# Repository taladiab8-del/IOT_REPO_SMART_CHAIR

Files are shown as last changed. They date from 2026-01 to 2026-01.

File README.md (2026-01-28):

# Smart Chair

## About The Project
We are the students: **Tala Diab, Bshara Awwad, Kayan Deeb**.

our project is a smart chair system that detects sitting posture in real time using pressure and motion sensors and displays the results in an application. The system supports real-time posture detection, cloud-based posture tracking with history storage, and daily and weekly posture reports. It is unique in combining pressure-based and motion-based posture recognition, supporting multiple users with baseline recalibration, and running an embedded KNN machine-learning model directly on an ESP32 microcontroller.

---

## Our Project in Details
We use **two modes** in the project: **Training mode** and **Prediction mode**.

### Training mode (building the dataset)
Training mode is used to **build a larger dataset** that will later be used to predict the user’s posture using the **KNN** machine‑learning model.

**How it works:**
1. **Baseline step:** the user first sits in **Position #1 (straight back)** so the system can save a **baseline** (to support different users and recalibration).
2. The user then goes through the **6 supported positions** (1–6).
3. For each position:
   - The user indicates **which position it is**.
   - The ESP32 samples the **5 FSR sensors + MPU6050** and collects the data.
   - The sample is appended to our **dataset Excel file** (under `DataSet/`) that stores all labeled samples.

**note (button / switch behavior):**
- Each time the user wants to record a **new position sample**, they toggle the **training trigger** from **OFF → ON** (and follow the on‑screen / printed instructions).  
  This ensures each labeled sample is saved as a separate entry in the dataset.

### Prediction mode (real-time inference)
Prediction mode is used to **predict the current sitting posture** using the existing dataset and the embedded **KNN** model.

**How it works (step-by-step):**
1. **Run the prediction firmware** on the ESP32.
2. **Press the button to start.**
3. The user first sits in **Position #1 (straight back)** to save a **baseline**.
   - The baseline is saved to **personalize** the system and reduce the effect of user‑specific factors (e.g., weight distribution and individual seating style) that can affect prediction.
4. After baseline is saved, the user can sit in any posture. The ESP32 continuously predicts the posture using the **dataset + KNN model**.
5. The predicted posture is uploaded to **Firebase**, and the app shows the result immediately.

**Live update rate:**
- The Live Data screen is updated **every 10 seconds** or **immediately when the posture changes**.

---

## Supported Positions (Labels 1–6)
1) Normal sitting (straight back)  
2) Left leg up  
3) Right leg up  
4) Leaning forward  
5) Reclined / tilted back  
6) Rotational / moving posture (motion state)

---

## application (Flutter) – what’s inside
The Flutter app is connected to Firebase and supports **three users**. For each user, the app provides:

### 1) Live Data screen
- Shows the **current posture label** in real time.
- Updates **every 10 seconds** or **when the user changes posture**.

### 2) Daily Report
- Shows **total sitting time today**.
- Shows **which postures were used today**, including counts / distribution (e.g., how many times each posture was detected).

### 3) Weekly Report
- Similar to Daily Report, but aggregated over the **current week**.
- Includes a **comparison vs. last week** for the same user.

### Sitting-duration alert + mute
- If a user remains sitting continuously for **1 hour**, the app shows a **“Move”** message.
- The message can be muted using a **Mute** button so the notifications stop appearing. **Muting does not reset the sitting timer** (the timer keeps running).
- Standing up resets the sitting timer and allows future alerts.

---

## Folder Description
In this git you have the following folders:

- `code/` – application code (Arduino + Python)
  - `code/arduino_code/chair_predict/`
    - `chair_predict.ino` – Prediction mode firmware 
    - `dataset.h` – exported dataset/KNN parameters header
  - `code/arduino_code/chair_training/`
    - `chair_training.ino` – Training mode firmware (collects labeled samples)
  - `code/pyhton_code/`
    - `build_dataset.py` – builds/updates the dataset file during Training
    - `export_knn.py` – exports the KNN model/parameters into `dataset.h`
    - `dataset.h` – generated header ny running export_knn.py
    - `sensor_samples.xlsx` – dataset from training

- `flutter_app/`
  - `lib/` – **our main app code**.

- `DataSet/` – contains the dataset Excel file (`sensor_samples.xlsx`)
- `Positions/` – contains the image of the supported sitting positions (`positions.png`)
- `Documentation/` – contains the poster and the connection diagram (PNG + Fritzing `.fzz`)
- `Unit Tests/` – unit tests for individual hardware components (button / pressure sensor / motion sensor)

---

## Hardware

### Hardware Components
- 5 × FSR pressure sensors
- 1 × MPU6050 motion sensor (IMU)
- 5 × 300Ω resistors
- 1 × ON/OFF switch
- 1 × ESP32 microcontroller

---

## Used Libraries

### Arduino/ESP32 libraries used in this project
  - `WiFi.h`
  - `Wire.h`
  - `time.h`
- Firebase ESP Client:
  - `Firebase_ESP_Client.h`
  - `addons/TokenHelper.h`
  - `addons/RTDBHelper.h`
- Adafruit MPU6050:
  - `Adafruit_MPU6050.h`
- Adafruit Unified Sensor:
  - `Adafruit_Sensor.h`

---

## Connection diagram

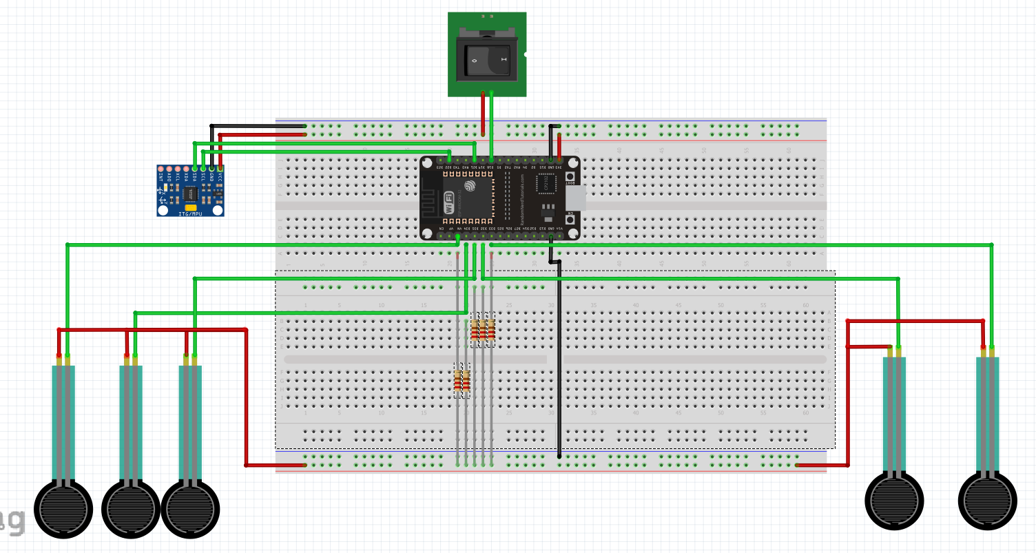
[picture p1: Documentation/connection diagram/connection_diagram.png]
Connection diagram


---

## Project Poster

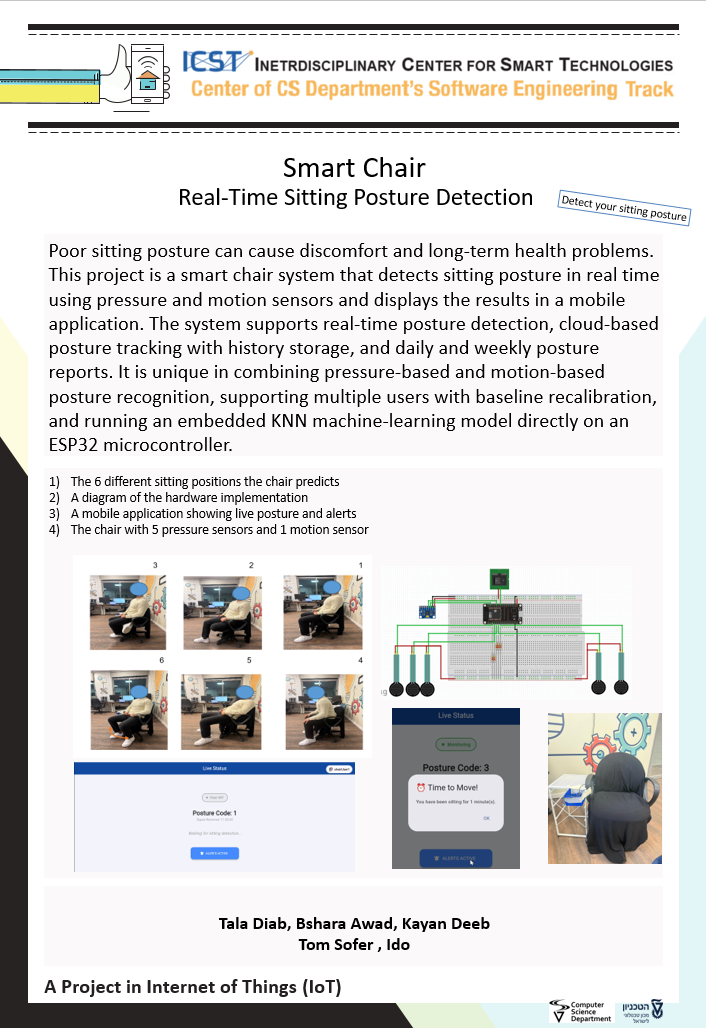
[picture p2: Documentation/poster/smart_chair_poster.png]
Smart Chair Poster


This project is part of ICST - The Interdisciplinary Center for Smart Technologies, Taub Faculty of Computer Science, Technion
https://icst.cs.technion.ac.il/

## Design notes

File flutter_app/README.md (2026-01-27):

# smart_chair

A new Flutter project.

## Getting Started

This project is a starting point for a Flutter application.

A few resources to get you started if this is your first Flutter project:

- [Lab: Write your first Flutter app](https://docs.flutter.dev/get-started/codelab)
- [Cookbook: Useful Flutter samples](https://docs.flutter.dev/cookbook)

For help getting started with Flutter development, view the
[online documentation](https://docs.flutter.dev/), which offers tutorials,
samples, guidance on mobile development, and a full API reference.

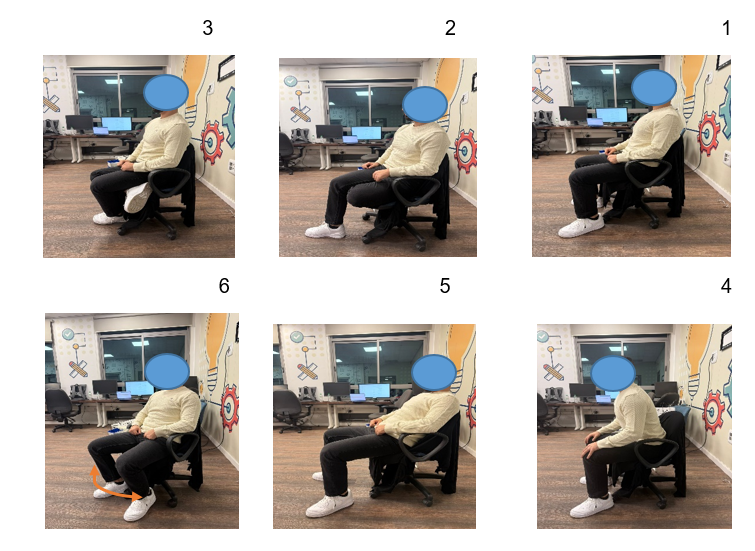
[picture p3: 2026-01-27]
Positions/positions.png

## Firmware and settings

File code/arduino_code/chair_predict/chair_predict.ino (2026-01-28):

// chair_predict.ino
// Live mode:
// - Switch ON  => continuous sampling/prediction
// - Send to app (Firebase) every 10s OR immediately when posture changes
// - Switch OFF => stop sending + RESET BASELINE 
//
// Motion gate (gyro deviation from baseline bias) => label 6
// Else KNN on normalized FSR features => labels 1..5
// KNN Features must match dataset.h order: [dp1..dp5, p1..p5, r]

#include <Wire.h>
#include <math.h>
#include <Adafruit_MPU6050.h>
#include <Adafruit_Sensor.h>

#include "dataset.h"   // N_SAMPLES, N_FEATURES(=11), FEATURE_MEAN, FEATURE_STD, TRAIN_SAMPLES, TRAIN_LABELS

#include <WiFi.h>
#include <Firebase_ESP_Client.h>
#include <time.h>
#include "addons/TokenHelper.h"
#include "addons/RTDBHelper.h"

// ---------- WiFi ----------
#define WIFI_SSID ""
#define WIFI_PASSWORD ""

// ---------- Firebase ----------
#define API_KEY ""
#define DATABASE_URL ""
#define USER_EMAIL ""
#define USER_PASSWORD ""

FirebaseData fbdo;
FirebaseAuth auth;
FirebaseConfig config;

String activeUserId = "chairUser1";
const char* chairId = "chair1";
unsigned long lastUserPollMs = 0;

// --------- Pins ----------
const int sensor1Pin = 35;
const int sensor2Pin = 39;
const int sensor3Pin = 33;
const int sensor4Pin = 34;
const int sensor5Pin = 32;

const int switchPin  = 18;

// --------- MPU ----------
Adafruit_MPU6050 mpu;

// --------- Sampling window ----------
const int N_SAMPLES_AVG   = 60;  
const int SAMPLE_DELAY_MS = 25;  

// --------- Sending policy ----------
const unsigned long LIVE_PERIOD_MS     = 10000; // periodic send every 10s
const unsigned long MIN_CHANGE_GAP_MS  = 1500;  

int lastSentPrediction = -1;
unsigned long lastSendMs = 0;

// --------- History throttling ----------
unsigned long lastHistoryPushMs = 0;
const unsigned long HISTORY_MIN_INTERVAL_MS = 60000; 
int lastHistoryPrediction = -1;

// --------- Motion thresholds (gyro deviation from baseline bias, rad/s) ----------
const float GYRO_DEV_TH_AVG = 0.30f;
const float GYRO_DEV_TH_MAX = 0.80f;

// --------- Baseline for FSR normalized features ----------
bool baselineSet = false;
float pb[5] = {0, 0, 0, 0, 0};   // baseline distribution p_i
float Bsum  = 0.0f;              // baseline total load
const float EPS_F = 1.0f;      

// --------- Gyro bias captured at baseline ----------
bool gyroBiasSet = false;
float gx0 = 0.0f, gy0 = 0.0f, gz0 = 0.0f;

// --------- For switch OFF detection ----------
bool prevSwitchOn = false;

// ===================== Utility =====================
void resetBaseline() {
  baselineSet = false;
  Bsum = 0.0f;
  for (int i = 0; i < 5; i++) pb[i] = 0.0f;

  gyroBiasSet = false;
  gx0 = gy0 = gz0 = 0.0f;

  lastSentPrediction = -1;
  lastSendMs = 0;
}

void readMPU(float &ax, float &ay, float &az,
             float &gx, float &gy, float &gz) {
  sensors_event_t a, g, temp;
  mpu.getEvent(&a, &g, &temp);

  ax = a.acceleration.x;
  ay = a.acceleration.y;
  az = a.acceleration.z;

  gx = g.gyro.x; // rad/s
  gy = g.gyro.y;
  gz = g.gyro.z;
}

// ===================== WiFi/Firebase =====================
void connectWiFi() {
  Serial.println("== WIFI ==");
  WiFi.mode(WIFI_STA);
  WiFi.begin(WIFI_SSID, WIFI_PASSWORD);

  Serial.print("Connecting to WiFi");
  unsigned long start = millis();
  while (WiFi.status() != WL_CONNECTED && millis() - start < 20000) {
    Serial.print(".");
    delay(400);
  }
  Serial.println();

  if (WiFi.status() == WL_CONNECTED) {
    Serial.print("WiFi connected. IP: ");
    Serial.println(WiFi.localIP());
  } else {
    Serial.println("WiFi FAILED.");
  }
}

void initTime() {
  Serial.println("== TIME ==");
  configTime(0, 0, "pool.ntp.org", "time.nist.gov");

  Serial.print("Syncing time");
  unsigned long start = millis();
  time_t now = time(nullptr);

  while (now < 1700000000 && millis() - start < 15000) {
    Serial.print(".");
    delay(300);
    now = time(nullptr);
  }
  Serial.println();

  if (now >= 1700000000) Serial.println("Time OK.");
  else Serial.println("Time sync FAILED. Continuing...");
}

void initFirebase() {
  Serial.println("== FIREBASE ==");
  config.api_key = API_KEY;
  config.database_url = DATABASE_URL;

  auth.user.email = USER_EMAIL;
  auth.user.password = USER_PASSWORD;

  Firebase.reconnectWiFi(true);
  fbdo.setResponseSize(2048);

  Firebase.begin(&config, &auth);

  Serial.print("Waiting for Firebase");
  unsigned long start = millis();
  while (!Firebase.ready() && millis() - start < 20000) {
    Serial.print(".");
    delay(300);
  }
  Serial.println();

  if (Firebase.ready()) Serial.println("Firebase ready");
  else Serial.println("Firebase NOT ready");
}

bool sendPredictionToFirebase(int prediction) {
  if (!Firebase.ready()) return false;

  FirebaseJson json;
  json.set("prediction", prediction);
  json.set("ts", (int)time(nullptr));
  json.set("device", "esp32");

  String path = "/users/" + activeUserId + "/live/posture";
  bool ok = Firebase.RTDB.setJSON(&fbdo, path.c_str(), &json);
  if (!ok) {
    Serial.print("RTDB live write failed: ");
    Serial.println(fbdo.errorReason());
  }
  return ok;
}

bool pushHistoryIfAllowed(int prediction) {
  if (!Firebase.ready()) return false;

  unsigned long nowMs = millis();
  bool enoughTime = (nowMs - lastHistoryPushMs) >= HISTORY_MIN_INTERVAL_MS;
  bool changed    = (prediction != lastHistoryPrediction);

  if (!enoughTime && !changed) return true;

  time_t now = time(nullptr);
  struct tm *t = gmtime(&now);

  char dateKey[11];
  snprintf(dateKey, sizeof(dateKey), "%04d-%02d-%02d",
           t->tm_year + 1900, t->tm_mon + 1, t->tm_mday);

  FirebaseJson json;
  json.set("prediction", prediction);
  json.set("ts", (int)now);
  json.set("device", "esp32");

  String path = "/users/" + activeUserId + "/history/" + String(dateKey);

  bool ok = Firebase.RTDB.pushJSON(&fbdo, path.c_str(), &json);
  if (!ok) {
    Serial.print("RTDB history push failed: ");
    Serial.println(fbdo.errorReason());
    return false;
  }

  lastHistoryPushMs = nowMs;
  lastHistoryPrediction = prediction;
  return true;
}

void updateActiveUserFromFirebase() {
  if (!Firebase.ready()) return;

  if (millis() - lastUserPollMs < 3000) return;
  lastUserPollMs = millis();

  String path = String("/chairs/") + chairId + "/activeUserId";
  if (Firebase.RTDB.getString(&fbdo, path.c_str())) {
    String newUser = fbdo.stringData();
    newUser.trim();

    if (newUser.length() > 0 && newUser != activeUserId) {
      activeUserId = newUser;

      // reset baseline for new user
      resetBaseline();

      Serial.print("Active user updated: ");
      Serial.println(activeUserId);
      Serial.println("Baseline reset. Keep switch ON while sitting NORMAL to capture baseline.");
    }
  }
}

// ===================== KNN =====================
void scaleFeatures(const float input[N_FEATURES], float output[N_FEATURES]) {
  for (int j = 0; j < N_FEATURES; ++j) {
    float stdv = FEATURE_STD[j];
    if (stdv == 0.0f) stdv = 1.0f;
    output[j] = (input[j] - FEATURE_MEAN[j]) / stdv;
  }
}

int predictKNN(const float rawFeatures[N_FEATURES]) {
  float features[N_FEATURES];
  scaleFeatures(rawFeatures, features);

  const int K = 7;

  float bestDist[K];
  int bestLabel[K];
  for (int i = 0; i < K; ++i) {
    bestDist[i] = 1e30f;
    bestLabel[i] = -1;
  }

  for (int i = 0; i < N_SAMPLES; ++i) {
    float d = 0.0f;
    for (int j = 0; j < N_FEATURES; ++j) {
      float diff = features[j] - TRAIN_SAMPLES[i][j];
      d += diff * diff;
    }

    int worstIndex = 0;
    float worstDist = bestDist[0];
    for (int t = 1; t < K; ++t) {
      if (bestDist[t] > worstDist) {
        worstDist = bestDist[t];
        worstIndex = t;
      }
    }

    if (d < worstDist) {
      bestDist[worstIndex] = d;
      bestLabel[worstIndex] = TRAIN_LABELS[i];
    }
  }

  int counts[16];
  for (int i = 0; i < 16; ++i) counts[i] = 0;

  for (int i = 0; i < K; ++i) {
    int lbl = bestLabel[i];
    if (lbl >= 0 && lbl < 16) counts[lbl]++;
  }

  int bestLbl = -1;
  int bestCount = -1;
  for (int lbl = 0; lbl < 16; ++lbl) {
    if (counts[lbl] > bestCount) {
      bestCount = counts[lbl];
      bestLbl = lbl;
    }
  }
  return bestLbl;
}

// ===================== Sample -> predict once =====================
bool sampleAndPredictOnce(int &outPrediction) {
  long s1_sum = 0, s2_sum = 0, s3_sum = 0, s4_sum = 0, s5_sum = 0;

  float gx_sum = 0.0f, gy_sum = 0.0f, gz_sum = 0.0f;

  float gyroDev_sum = 0.0f;
  float gyroDev_max = 0.0f;

  for (int i = 0; i < N_SAMPLES_AVG; i++) {
    int v1 = analogRead(sensor1Pin);
    int v2 = analogRead(sensor2Pin);
    int v3 = analogRead(sensor3Pin);
    int v4 = analogRead(sensor4Pin);
    int v5 = analogRead(sensor5Pin);

    s1_sum += v1; s2_sum += v2; s3_sum += v3; s4_sum += v4; s5_sum += v5;

    float ax, ay, az, gx, gy, gz;
    readMPU(ax, ay, az, gx, gy, gz);

    gx_sum += gx; gy_sum += gy; gz_sum += gz;

    if (gyroBiasSet) {
      float dx = gx - gx0;
      float dy = gy - gy0;
      float dz = gz - gz0;
      float dev = sqrtf(dx*dx + dy*dy + dz*dz);
      gyroDev_sum += dev;
      if (dev > gyroDev_max) gyroDev_max = dev;
    }

    delay(SAMPLE_DELAY_MS);
  }

  float s1 = s1_sum / (float)N_SAMPLES_AVG;
  float s2 = s2_sum / (float)N_SAMPLES_AVG;
  float s3 = s3_sum / (float)N_SAMPLES_AVG;
  float s4 = s4_sum / (float)N_SAMPLES_AVG;
  float s5 = s5_sum / (float)N_SAMPLES_AVG;

  float gx_avg = gx_sum / (float)N_SAMPLES_AVG;
  float gy_avg = gy_sum / (float)N_SAMPLES_AVG;
  float gz_avg = gz_sum / (float)N_SAMPLES_AVG;

  // ----- baseline capture -----
  if (!baselineSet) {
    float Sbase = s1 + s2 + s3 + s4 + s5;
    Bsum = Sbase;

    pb[0] = s1 / (Sbase + EPS_F);
    pb[1] = s2 / (Sbase + EPS_F);
    pb[2] = s3 / (Sbase + EPS_F);
    pb[3] = s4 / (Sbase + EPS_F);
    pb[4] = s5 / (Sbase + EPS_F);

    gx0 = gx_avg; gy0 = gy_avg; gz0 = gz_avg;
    gyroBiasSet = true;

    baselineSet = true;

    Serial.println("BASELINE_SAVED. Predictions will start now.");
    return false;
  }

  // ----- motion gate -----
  float gyroDev_avg = gyroDev_sum / (float)N_SAMPLES_AVG;

  if (gyroDev_avg > GYRO_DEV_TH_AVG || gyroDev_max > GYRO_DEV_TH_MAX) {
    outPrediction = 6;
    return true;
  }

  // ----- KNN features -----
  float S = s1 + s2 + s3 + s4 + s5;

  float p1 = s1 / (S + EPS_F);
  float p2 = s2 / (S + EPS_F);
  float p3 = s3 / (S + EPS_F);
  float p4 = s4 / (S + EPS_F);
  float p5 = s5 / (S + EPS_F);

  float dp1 = p1 - pb[0];
  float dp2 = p2 - pb[1];
  float dp3 = p3 - pb[2];
  float dp4 = p4 - pb[3];
  float dp5 = p5 - pb[4];

  float r = logf((S + EPS_F) / (Bsum + EPS_F));

  float rawFeatures[N_FEATURES] = {
    dp1, dp2, dp3, dp4, dp5,
    p1,  p2,  p3,  p4,  p5,
    r
  };

  outPrediction = predictKNN(rawFeatures);
  return true;
}

// ===================== Setup/Loop =====================
void setup() {
  Serial.begin(115200);
  delay(1500);

  pinMode(switchPin, INPUT_PULLDOWN);

  pinMode(sensor1Pin, INPUT);
  pinMode(sensor2Pin, INPUT);
  pinMode(sensor3Pin, INPUT);
  pinMode(sensor4Pin, INPUT);
  pinMode(sensor5Pin, INPUT);

  Wire.begin();

  Serial.println("== MPU6050 ==");
  if (!mpu.begin()) {
    Serial.println("Failed to find MPU6050 chip");
    while (1) delay(10);
  }
  mpu.setAccelerometerRange(MPU6050_RANGE_4_G);
  mpu.setGyroRange(MPU6050_RANGE_500_DEG);
  mpu.setFilterBandwidth(MPU6050_BAND_21_HZ);
  Serial.println("MPU ready");

  connectWiFi();
  if (WiFi.status() == WL_CONNECTED) {
    initTime();
    initFirebase();
  } else {
    Serial.println("WiFi not connected; Firebase disabled.");
  }

  Serial.println("=== LIVE MODE ===");
  Serial.println("Switch ON  => continuous sampling, send every 10s OR on change.");
  Serial.println("Switch OFF => stop + reset baseline.");
  Serial.println("After turning ON, sit NORMAL (no motion) to capture baseline first.");
}

void loop() {
  updateActiveUserFromFirebase();

  bool isOn = (digitalRead(switchPin) == HIGH);

  // Detect ON->OFF: reset baseline
  if (!isOn && prevSwitchOn) {
    Serial.println("Switch OFF -> stopping live + resetting baseline.");
    resetBaseline();
  }
  prevSwitchOn = isOn;

  if (!isOn) {
    delay(50);
    return;
  }

  // Live: sample continuously
  int prediction = -1;
  bool hasPred = sampleAndPredictOnce(prediction);

  if (!hasPred) {
    delay(20);
    return;
  }

  Serial.print("Pred = ");
  Serial.println(prediction);

  // Send policy: every 10s OR immediately when changed 
  unsigned long nowMs = millis();
  bool periodicDue = (nowMs - lastSendMs) >= LIVE_PERIOD_MS;
  bool changedDue  = (prediction != lastSentPrediction) && ((nowMs - lastSendMs) >= MIN_CHANGE_GAP_MS);

  if (periodicDue || changedDue) {
    Serial.print("Sending to Firebase (reason=");
    Serial.print(periodicDue ? "periodic" : "change");
    Serial.println(")");

    if (sendPredictionToFirebase(prediction)) {
      pushHistoryIfAllowed(prediction);
      lastSendMs = nowMs;
      lastSentPrediction = prediction;
    } else {
      Serial.println("Firebase send failed.");
    }
  }

  delay(10);
}

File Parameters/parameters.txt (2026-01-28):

maxSittingMinutes  | flutter_app/lib/screens/live_screen.dart (_LiveScreenState) | Minutes of continuous sitting before showing "Time to Move" alert.
signalTimeoutSeconds | flutter_app/lib/screens/live_screen.dart (_LiveScreenState) | If no ESP32 signal received for this many seconds, chair is considered OFF.

defaultUserId  | flutter_app/lib/state/active_user.dart (ActiveUser) | Default selected userId when the app starts (before choosing a different user).
defaultMuted  | flutter_app/lib/state/active_user.dart (ActiveUser) | Default alert mute state when the app starts (false = alerts active).

N_SAMPLES_AVG | code\arduino_code\chair_training.ino | Number of samples averaged per capture.
SAMPLE_DELAY_MS  | code\arduino_code\chair_training.ino | Delay between samples during averaging.

N_SAMPLES_AVG  | code\arduino_code\chair_predict.ino | Number of samples averaged per prediction cycle (higher = smoother but slower reaction).
SAMPLE_DELAY_MS | code\arduino_code\chair_predict.ino | Delay between samples during averaging (controls prediction update rate).
LIVE_PERIOD_MS  | code\arduino_code\chair_predict.ino | Send prediction to Firebase at least once every this many ms (periodic keep-alive).
HISTORY_MIN_INTERVAL_MS | code\arduino_code\chair_predict.ino | Minimum interval between history writes unless prediction changed.
GYRO_DEV_TH_AVG | code\arduino_code\chair_predict.ino | Motion gate threshold on average gyro deviation from baseline.
GYRO_DEV_TH_MAX | code\arduino_code\chair_predict.ino | Motion gate threshold on max gyro deviation from baseline.
KNN_K | code\arduino_code\chair_predict.ino (predictKNN) | K value for KNN voting.

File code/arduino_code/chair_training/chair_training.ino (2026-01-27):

// chair_training.ino
// Training RAW streaming for Excel that has columns:
// s1..s11, label, b1..b5, p1, dp1, p2, dp2, p3, dp3, p4, dp4, p5, dp5, r
//
// Flow:
// 1) First OFF->ON captures BASELINE (sit normal): prints BASELINE_SAVED + BASE_RAW_CSV
// 2) Every next OFF->ON prints SAMPLE_RAW_CSV + END_SAMPLE
//
// Python script will ask label and will compute p/dp/r and fill b1..b5.

#include <Wire.h>
#include <math.h>
#include <Adafruit_MPU6050.h>
#include <Adafruit_Sensor.h>

// --------- Pins ----------
const int sensor1Pin = 35;
const int sensor2Pin = 39;
const int sensor3Pin = 33;
const int sensor4Pin = 34;
const int sensor5Pin = 32;

const int switchPin  = 18;   // ON/OFF switch

Adafruit_MPU6050 mpu;

// switch edge detect
int lastSwitchState = LOW;

// --------- Sampling window ----------
const int N_SAMPLES_AVG   = 50; 
const int SAMPLE_DELAY_MS = 80;  

// --------- Baseline state (FSR only) ----------
bool baselineSet = false;
float baseFSR[5] = {0,0,0,0,0};

// ---------- Read MPU ----------
static inline void readMPU(float &ax, float &ay, float &az,
                           float &gx, float &gy, float &gz) {
  sensors_event_t a, g, temp;
  mpu.getEvent(&a, &g, &temp);

  ax = a.acceleration.x;
  ay = a.acceleration.y;
  az = a.acceleration.z;

  gx = g.gyro.x;
  gy = g.gyro.y;
  gz = g.gyro.z;
}

void sampleAverages(float &s1, float &s2, float &s3, float &s4, float &s5,
                    float &ax, float &ay, float &az,
                    float &gx, float &gy, float &gz) {
  long s1_sum=0, s2_sum=0, s3_sum=0, s4_sum=0, s5_sum=0;
  float ax_sum=0, ay_sum=0, az_sum=0, gx_sum=0, gy_sum=0, gz_sum=0;

  for (int i = 0; i < N_SAMPLES_AVG; i++) {
    s1_sum += analogRead(sensor1Pin);
    s2_sum += analogRead(sensor2Pin);
    s3_sum += analogRead(sensor3Pin);
    s4_sum += analogRead(sensor4Pin);
    s5_sum += analogRead(sensor5Pin);

    float _ax,_ay,_az,_gx,_gy,_gz;
    readMPU(_ax,_ay,_az,_gx,_gy,_gz);
    ax_sum += _ax; ay_sum += _ay; az_sum += _az;
    gx_sum += _gx; gy_sum += _gy; gz_sum += _gz;

    delay(SAMPLE_DELAY_MS);
  }

  s1 = s1_sum / (float)N_SAMPLES_AVG;
  s2 = s2_sum / (float)N_SAMPLES_AVG;
  s3 = s3_sum / (float)N_SAMPLES_AVG;
  s4 = s4_sum / (float)N_SAMPLES_AVG;
  s5 = s5_sum / (float)N_SAMPLES_AVG;

  ax = ax_sum / (float)N_SAMPLES_AVG;
  ay = ay_sum / (float)N_SAMPLES_AVG;
  az = az_sum / (float)N_SAMPLES_AVG;

  gx = gx_sum / (float)N_SAMPLES_AVG;
  gy = gy_sum / (float)N_SAMPLES_AVG;
  gz = gz_sum / (float)N_SAMPLES_AVG;
}

void handleOffToOn() {
  Serial.println("Sampling...");

  float s1,s2,s3,s4,s5, ax,ay,az, gx,gy,gz;
  sampleAverages(s1,s2,s3,s4,s5, ax,ay,az, gx,gy,gz);

  if (!baselineSet) {
    baseFSR[0]=s1; baseFSR[1]=s2; baseFSR[2]=s3; baseFSR[3]=s4; baseFSR[4]=s5;
    baselineSet = true;

    Serial.println("BASELINE_SAVED");
    Serial.print("BASE_RAW_CSV=");
    Serial.print(baseFSR[0], 4); Serial.print(",");
    Serial.print(baseFSR[1], 4); Serial.print(",");
    Serial.print(baseFSR[2], 4); Serial.print(",");
    Serial.print(baseFSR[3], 4); Serial.print(",");
    Serial.println(baseFSR[4], 4);

    return;
  }

  Serial.print("SAMPLE_RAW_CSV=");
  Serial.print(s1, 4); Serial.print(",");
  Serial.print(s2, 4); Serial.print(",");
  Serial.print(s3, 4); Serial.print(",");
  Serial.print(s4, 4); Serial.print(",");
  Serial.print(s5, 4); Serial.print(",");
  Serial.print(ax, 4); Serial.print(",");
  Serial.print(ay, 4); Serial.print(",");
  Serial.print(az, 4); Serial.print(",");
  Serial.print(gx, 4); Serial.print(",");
  Serial.print(gy, 4); Serial.print(",");
  Serial.println(gz, 4);

  Serial.println("END_SAMPLE");
}

void setup() {
  Serial.begin(115200);
  delay(1500);

  pinMode(switchPin, INPUT_PULLDOWN);

  pinMode(sensor1Pin, INPUT);
  pinMode(sensor2Pin, INPUT);
  pinMode(sensor3Pin, INPUT);
  pinMode(sensor4Pin, INPUT);
  pinMode(sensor5Pin, INPUT);

  Wire.begin();
  if (!mpu.begin()) {
    Serial.println("Failed to find MPU6050 chip");
    while (1) delay(10);
  }
  mpu.setAccelerometerRange(MPU6050_RANGE_4_G);
  mpu.setGyroRange(MPU6050_RANGE_500_DEG);
  mpu.setFilterBandwidth(MPU6050_BAND_21_HZ);

  lastSwitchState = digitalRead(switchPin);

  Serial.println("TRAINING RAW MODE:");
  Serial.println("1) OFF->ON (first time): sit NORMAL -> capture baseline (FSR) only");
  Serial.println("2) OFF->ON (next times): outputs SAMPLE_RAW_CSV + END_SAMPLE (Python logs row)");
  Serial.print("N_SAMPLES_AVG="); Serial.print(N_SAMPLES_AVG);
  Serial.print(" SAMPLE_DELAY_MS="); Serial.println(SAMPLE_DELAY_MS);
}

void loop() {
  int currentState = digitalRead(switchPin);

  if (currentState != lastSwitchState) {
    delay(30);
    int confirmState = digitalRead(switchPin);

    if (confirmState == HIGH && lastSwitchState == LOW) {
      handleOffToOn();
    }

    lastSwitchState = confirmState;
  }

  delay(10);
}

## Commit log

2026-01-27 adding UNIT TESTS
    [sensor_samples.xlsx]
2026-01-27 add connection diagram
    [connection_diagram.fzz]
2026-01-28 add readme
    [parameters.txt]
